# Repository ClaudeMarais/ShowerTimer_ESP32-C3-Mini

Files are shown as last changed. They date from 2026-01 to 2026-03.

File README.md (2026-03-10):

# Shower Timer using ESP32-C3 Super Mini

An Arduino project that automatically detects if a shower is running and shows a timer for how long you’ve been showering. TinyML using microphone data is used to determine if the shower is running or not.

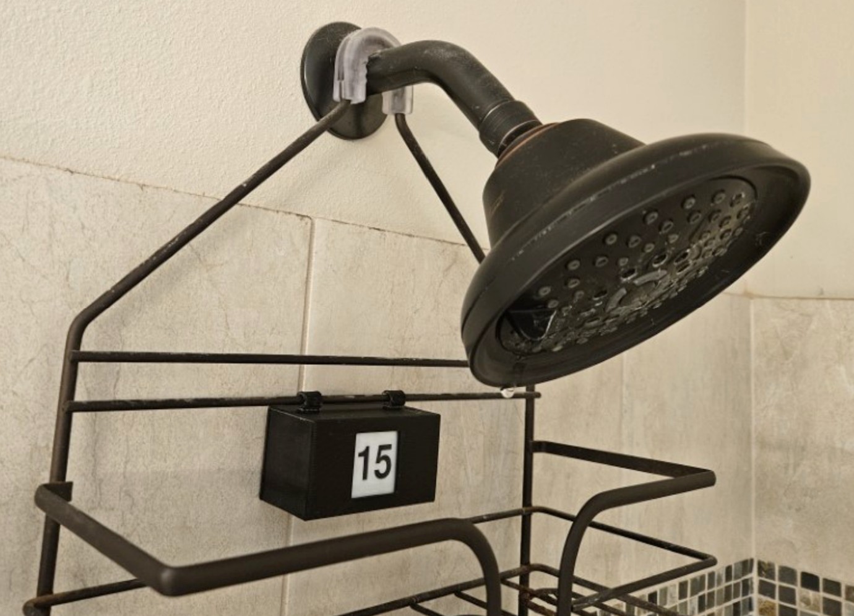
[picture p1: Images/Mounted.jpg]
Mounted


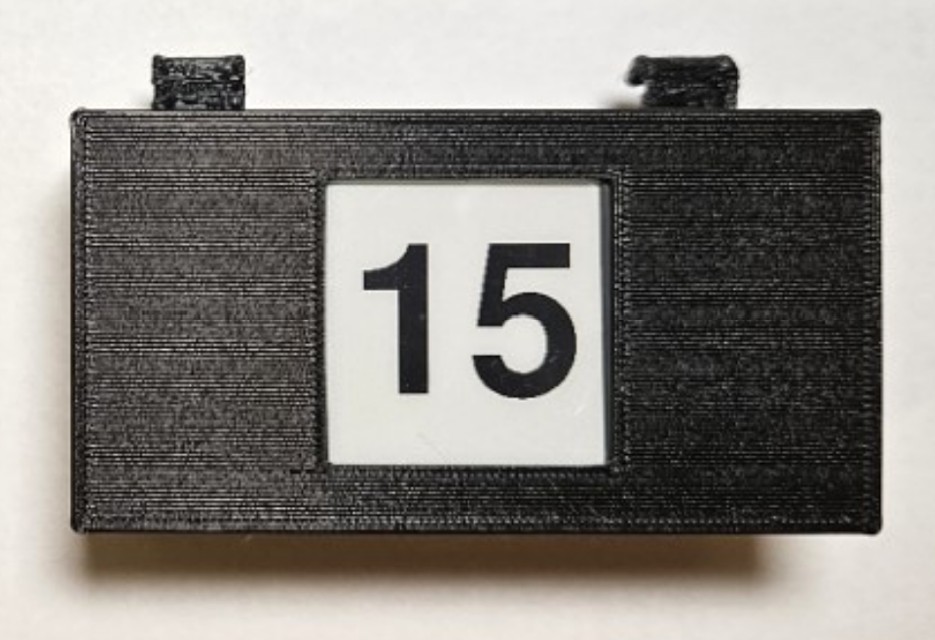
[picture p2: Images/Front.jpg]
Front


# Table of Contents
- [Introduction](#introduction)
- [Building your own](#building-your-own)
- [Building the device](#building-the-device)
- [Building the Arduino app](#building-the-arduino-app)
- [Creating your own ML model](#creating-your-own-ml-model)
- [Capturing ML training data](#capturing-ml-training-data)
- [Debugging inference results](#debugging-inference-results)
- [Detecting if the shower is ON/OFF](#detecting-if-the-shower-is-onoff)
- [Battery life](#battery-life)

---

# Introduction

An Arduino project that automatically detects if a shower is running and shows a timer for how long you’ve been showering. TinyML using microphone data is used to determine if the shower is running or not.

There are different ways to detect if the shower is on, e.g. small vibrations on the shower head could be detected using piezoelectric or gyroscope sensor. I tried a piezoelectric sensor, but the vibrations were too small to pick up, even though I could feel it with my hand. You could also modify the shower head pipe to install a small water flow sensor, but I didn't want to modify the shower. Therefore, I decided to use a small microphone.

This is a great machine learning application, since there are many different “white noises” in a bathroom, so it can be challenging to distinguish between them algorithmically. E.g. shower, hair dryer, filling a bathtub, toilet flush, extractor fan, electric toothbrush and shaver, vacuum cleaner, etc.

Since the device is in the shower, I had to waterproof it by cutting out two rubber gaskets, one sealing the display and one sealing the lid at the back. To protect the inside of the device from condensation, I applied transparent electronic silicone adhesive sealant on the circuit boards and solder points.

To conserve energy, an e-paper display is used which uses no power to display something. It only uses power to change something on the display, and that only happens once per minute while the shower is running.

This is considered version 1, which doesn't have fantastic battery life, since I didn't consider that even though the device goes into deepsleep, the microphone will still draw power at 1.4mA. This document includes a very detailed section on expected [battery life](#battery-life) and future improvements.

---

# Building your own

Building your own device involves
- [Building the actual device](#building-the-device)
- [Building the Arduino app](#building-the-arduino-app)
- Potentially [creating your own ML model](#creating-your-own-ml-model) if it doesn't work in your shower

<br>

| Folder | Note |
| --- |--- |
| ShowerTimer/ShowerTimer/ | Main Arduino project |
| ShowerTimer/ShowerTimer_inferencing.zip | Edge Impulse Arduino lib to install |
| ShowerTimer/3DModels/ | Models to 3D print |
| ShowerTimer/Android/CollectDataOnPhone  | Android project to collect ML training data |
| ShowerTimer/Android/DebugOnPhone | Android project to show debug info on phone |
| ShowerTimer/MLData.zip | My ML training audio recordings |

<br>

# Building the device

### **Image 1 - Components**

 - ESP32-C3 Super Mini
 - INMP441 i2s microphone
 - Waveshare 1.54inch E-Ink Display Module, black & white, 200x200 resolution, SPI interface
 - 0.8mm black silicone rubber
 - Battery holder for 3X 1.5V AAA batteries
 - PETG 3D printing filament

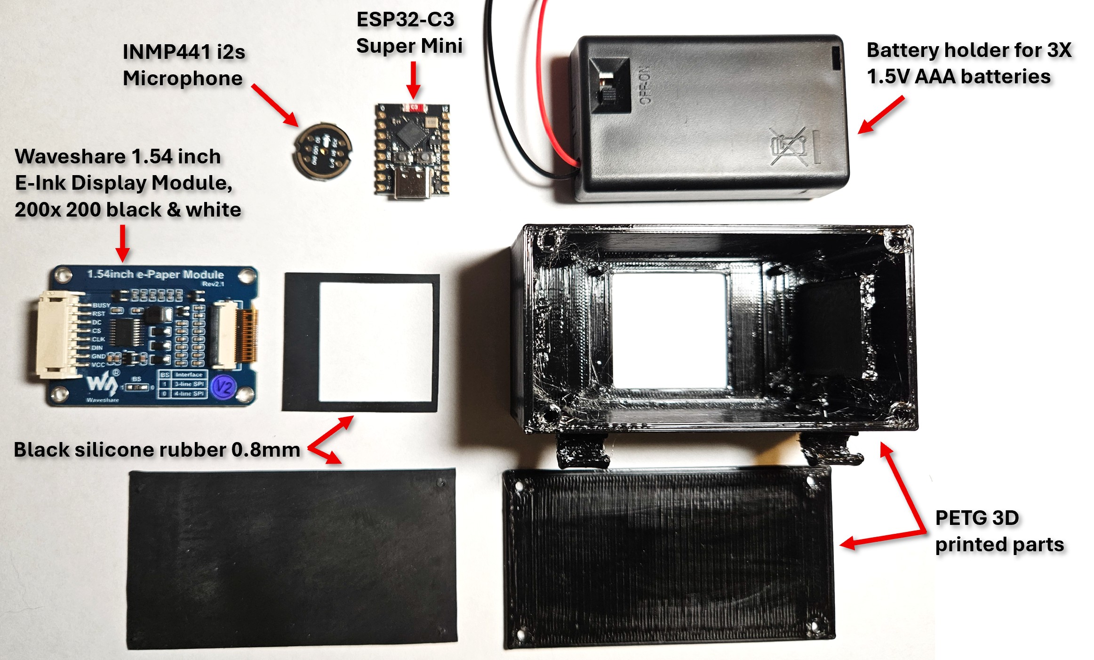
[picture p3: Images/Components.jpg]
Components


---

### **Image 2 - 3D design**

- [MatterControl](#https://www.matterhackers.com/store/l/mattercontrol/sk/MKZGTDW6) source files included if you need to make modifications
- Print with PETG or anything that won't warp with heat and humidity

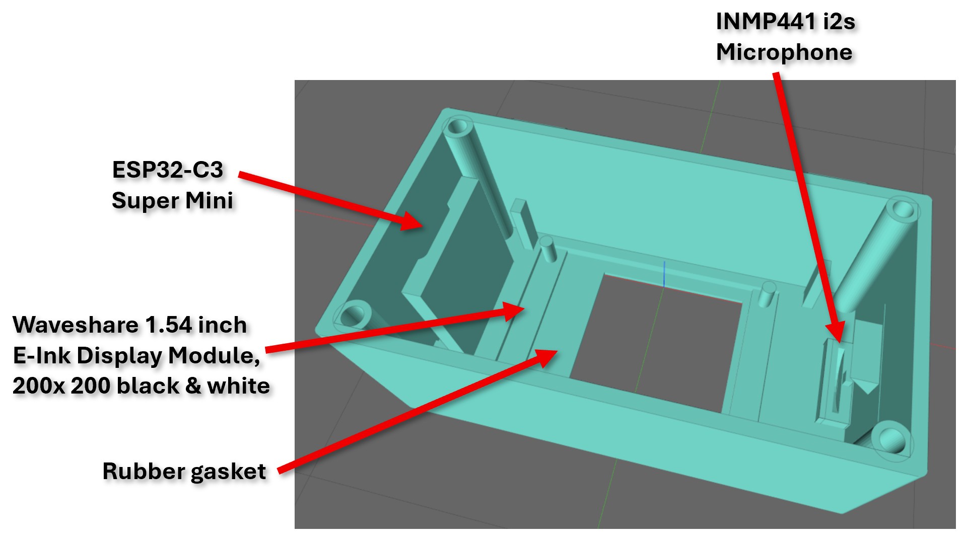
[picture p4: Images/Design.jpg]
Design


---

### **Image 3 - Component placement**

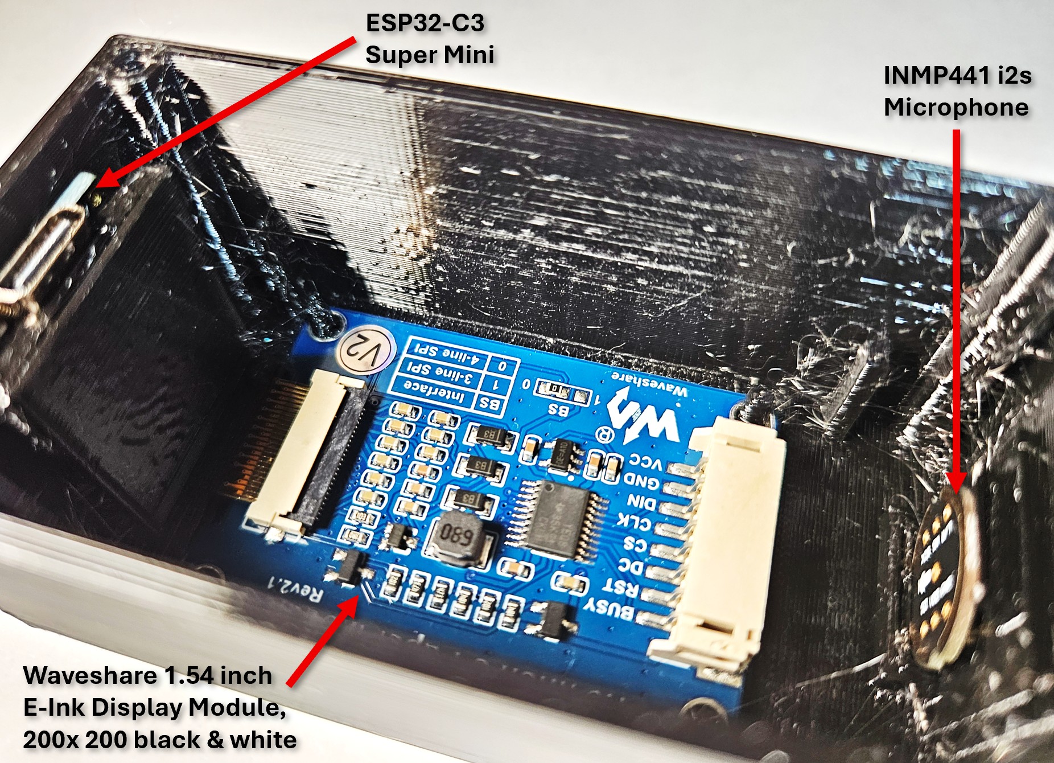
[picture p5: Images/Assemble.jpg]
Assemble


---

### **Image 4 - Wiring diagram**

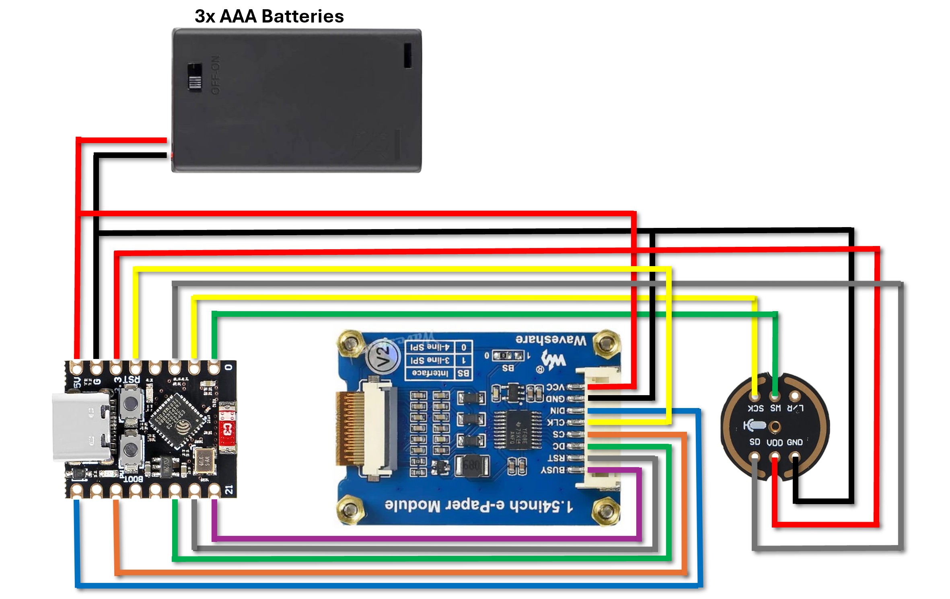
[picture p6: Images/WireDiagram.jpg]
WireDiagram

---

### **Image 5 - Soldered**

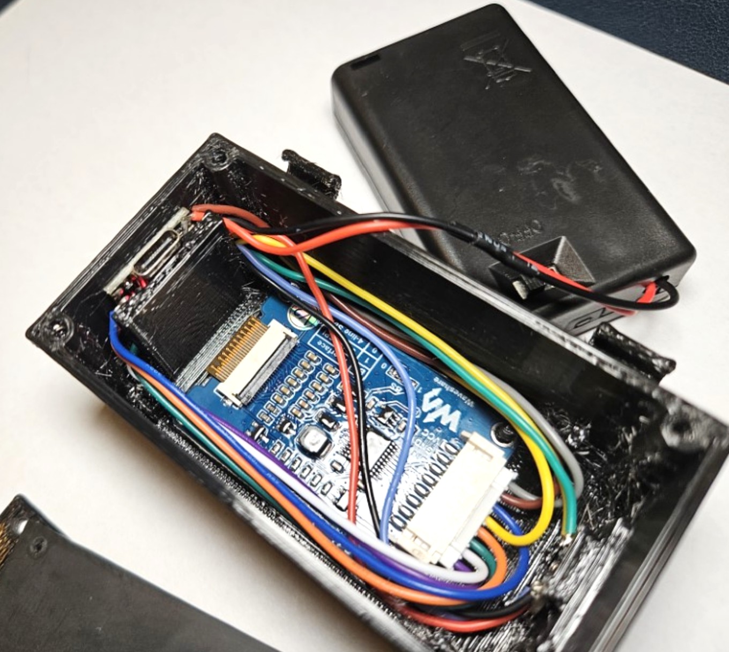
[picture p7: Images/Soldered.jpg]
Soldered


---

### **Image 6 - Waterproofing**

- Use sharp cutting tool or laser cutter to cut sealing gaskets out of 0.8mm silcone rubber sheet

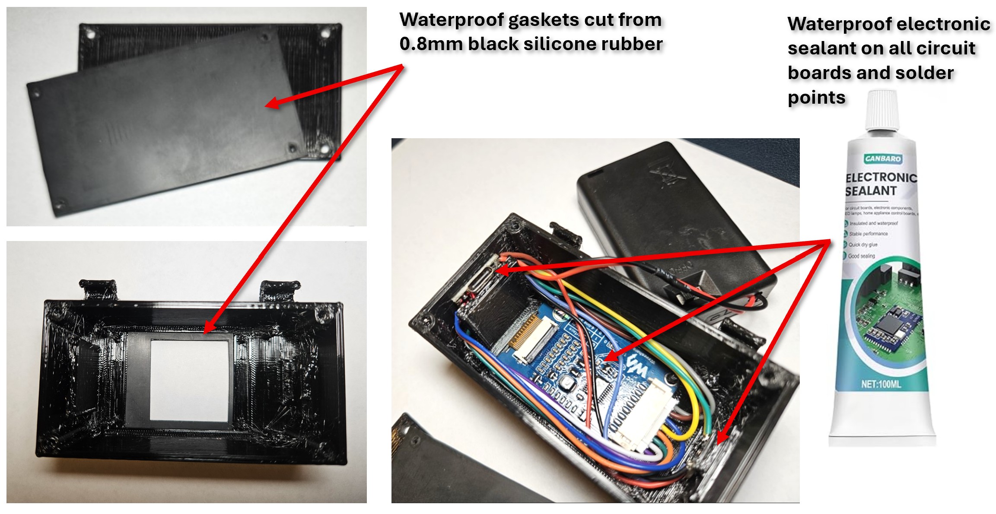
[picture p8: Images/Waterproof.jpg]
Waterproof


---

# Building the Arduino app

-	Install the Arduino IDE - https://www.arduino.cc/en/software
-	Configure Arduino IDE for ESP32 - https://randomnerdtutorials.com/installing-esp32-arduino-ide-2-0/
-	Install the below libraries - https://docs.arduino.cc/software/ide-v1/tutorials/installing-libraries/
    - Adafruit_GFX
    - [GxEPD2](https://github.com/ZinggJM/GxEPD2)
    - [ShowerTimer_inferencing](https://studio.edgeimpulse.com/public/879150/live) included as a zip file in this repro, generated by [Edge Impulse](https://www.edgeimpulse.com/)

For the final app, make sure to disable all defines for debugging and BLE connections. If not, your battery life will be extrememly short.

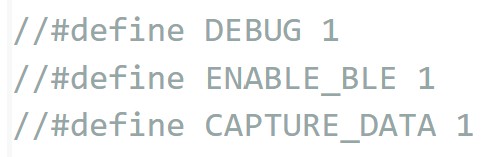
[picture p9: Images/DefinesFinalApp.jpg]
DefinesFinalApp


---

# Creating your own ML model

There’s a possibility that the device might not be accurate in your own bathroom, since your shower might sound different to mine, have different water pressure and water flow, different acoustics, different white noise, etc. In that case, you’ll need to build your own ML model using [Edge Impulse](#https://www.edgeimpulse.com/).

1) First, [build the device](#building-the-device) because you will need to close it up powered by batteries, and place it in your shower when capturing audio data. The shower will be on so you can’t have the device connected with wires that can get wet, and the acoustics will be different when the device is closed vs open.

2) Then, mount the device in your shower and [capture your own ML training data](#capturing-ml-training-data).

3) After that, clone my Edge Impulse project [ShowerTimer_inferencing](https://studio.edgeimpulse.com/public/879150/live) and add your own audio data to the project. It's a simple process, just follow documentation and examples.

4) Once added, click the button in Edge Impulse to retrain the model.

5) Click the button in Edge Impulse to export the model as an Arduino library. This will generate a .zip file that is similar to any other Ardauino library.

6) Replace the exsiting ShowerTimer_inferencing Arduino library with your own exported library.

7) Finally, rebuild the Arduino project.

---

# Capturing ML training data

ML will only work as well as your training data, i.e. bad training data will lead to poor results. Therefore, it's important to capture the training data exactly in the same way that you would use the device, i.e. similar location in the shower, similar everyday activities, device closed up for waterproofing, different water temperatures, etc.

Since the device will be closed up and installed in the shower, while the shower is running, data is captured and sent to your phone via BLE. This repo contains an Android app that connects with the device.

First, build the Arduino app with the following defines. Then, close it up and install it in the shower.

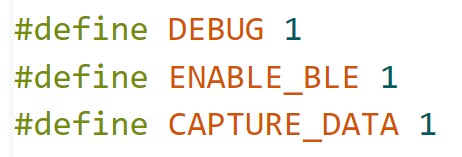
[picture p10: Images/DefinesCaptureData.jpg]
DefinesCaptureData
 

The folder "ShowerTimer/Android/CollectDataOnPhone" contains an Android app for recording the audio data. The device and phone will automatically connect via BLE, no need for any pairing. There are two buttons on the phone app to record data. Pressing one of these buttons will send a request to the Arduino device to reboot and immediately start an audio recording, and when done it will send it to the phone. You should see the progress bar at the top while recording and transfer is happening. The recordings can be found on your phone's storage in the folder "Internal storage/Documents/ShowerTimer/"

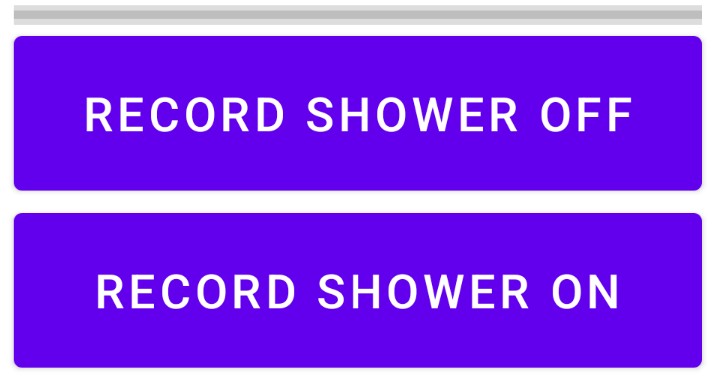
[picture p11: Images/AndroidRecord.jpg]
AndroidRecord


What to record? Well, you want to record as much of a variety of the day-to-day sounds in the bathroom. I suggest first recording as many sounds as possible with the shower door closed and the shower OFF. E.g. do multiple recordings for each case while the bathtub is being filled, extractor fan is on\off, hair dryer on difference speeds, vacuum cleaner sweeping through the bathroom, toilet flushes, electric toothbrush or shaver on, walking around, etc. Then, do many recordings when the shower is running, perhaps even redo some of previous scenarios where the shower was previously OFF, but now the shower is ON. I.e. do a few recordings of the hair dryer on and the shower is on. It’s very important to not just do recordings while the shower is running, but also when you are inside the shower, since this will create different sounds as larger water droplets form and splash against the side of the shower, etc. Also, the shower will sound different when running cold, warm or hot water, since the water pressure might be different in those cases.

---

# Debugging inference results

If you're lucky, you'll train the new model with your new data and everything just works. If not, you will need to somehow debug what the ML model produces, perhaps even while you are standing in the shower. The folder "ShowerTimer/Android/DebugOnPhone" contains an Android app that will display results from the Arduino device. This includes a loudness metric, the ML probability that the shower is on, and the actual result. The device and phone will automatically connect via BLE, no need for any pairing. Compile the Arduino app with the following defines.

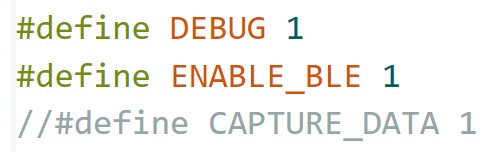
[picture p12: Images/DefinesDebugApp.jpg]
DefinesDebugApp


---

# Detecting if the shower is ON/OFF

Initially I thought this is a very simple problem to solve, since it’s very obvious when the shower is ON/OFF looking at the two graphics below which shows 250ms of audio data.

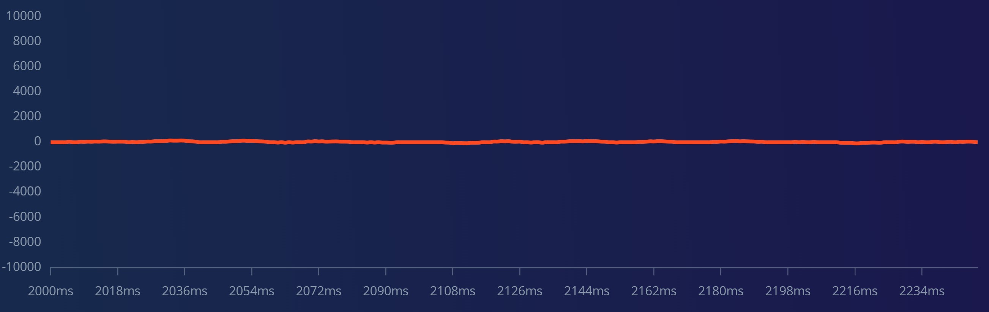
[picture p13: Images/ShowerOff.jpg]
ShowerOFF

*Figure 1 - Shower OFF*

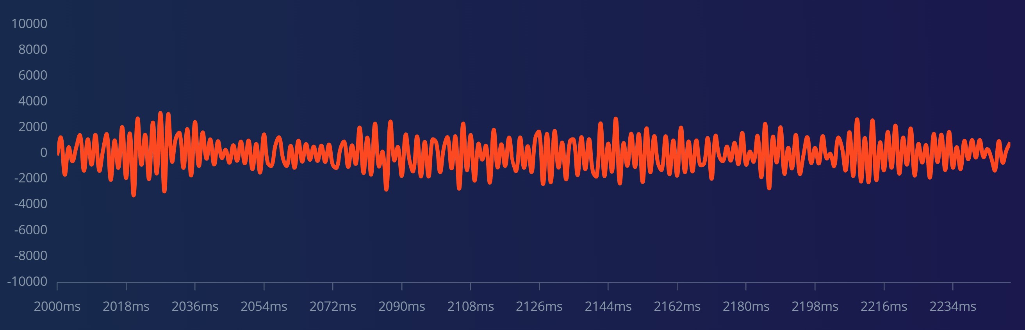
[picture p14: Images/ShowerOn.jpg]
ShowerON

*Figure 2 - Shower ON*

But, I quickly realized that this isn’t always the case, since there can be lots of “white” noises in a bathroom, including shower running, bathtub getting filled/drowned, extractor fan, toilet flush, hair dryer at different speeds, electric toothbrush and shaver, etc. Shower sounds also change when the water is hot, cold and with different water pressure. See the two graphs below.

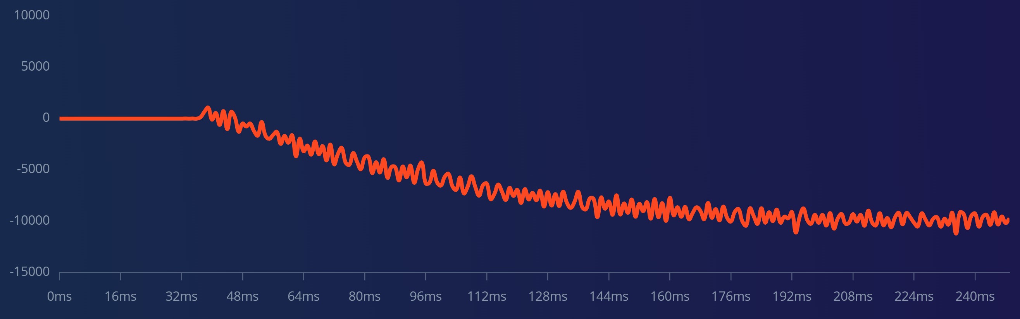
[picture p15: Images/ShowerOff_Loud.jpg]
ShowerOff_Loud

*Figure 3 - Hair dryer*

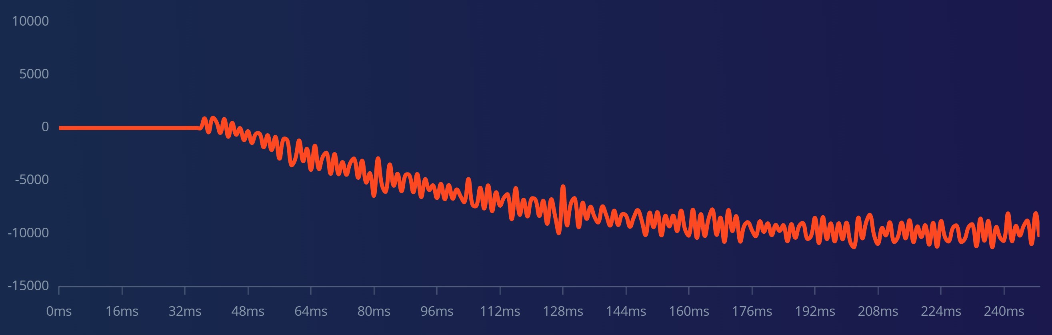
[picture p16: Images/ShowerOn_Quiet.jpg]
ShowerOn_Quiet

*Figure 4 - Shower ON*

 This let me decide to use [TinyML](#TinyML.org) as a solution, and it turned out to be fantastically reliable.

Initial results weren’t great though. The reason for this is that in order to save battery life, the device deepsleeps and right after it wakes up, it captures sound to process. The catch is that the microphone takes time to produce actual data, in my case 38ms, and after that it takes about 2 seconds to stabilize due to DC drift, we expect audio data to oscillate around zero. We expect data to show a straight line in a quiet environment, similar to Figure 1, but looking at the graph below there is a small section at the beginning of the graph that is just zero values, then a non-linear curve caused by DC drift, and only after about 2 seconds the data is stabilized, i.e. oscillating around zero.

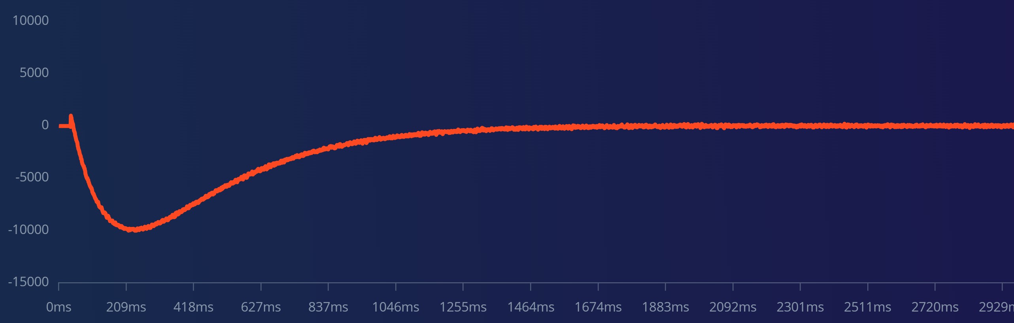
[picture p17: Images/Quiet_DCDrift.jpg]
Quiet_DCDrift

*Figure 5 - Non-linear audio data caused by DC drift*

 Training data was captured while the microphone already stabilized (Figure 1), but runtime inference was done while the microphone hasn’t produced data and was still unstable (Figure 3 & 4).

After realizing this, I captured new training data by starting the capture right after a wake from deepsleep. I also added a delay of 40ms after waking from a deepsleep to exclude any zeroed out data in the I2S DMA buffers from calling the API i2s_zero_dma_buffer(). This change gave an extremely reliable result, in fact I have yet to see a false positive or false negative!

I used Edge Impulse for my TinyML project, the full project with training data is available here: [Edge Impulse Shower Timer Project](https://studio.edgeimpulse.com/public/879150/live)

The design of the ML model is extremely simple. Audio MFE (Mel-frequency energy) is used as DSP (digital signal processing) to create ML features that is used as input into inferencing. The model itself basically consists of only two dense layers of 16 neurons each.

---

# Performance
Since the ML model is extremely simple, it is extremely fast to run on the microcontroller. Capturing the audio data and processing it take the majority of the time. A full cycle of the below takes 590ms on the ESP32-C3. For most of the day the bathroom will be quiet, and will run only for 260ms, which skips steps 4 and 5.
1)	Delay 40ms to wait for the microphone to start producing values
2)	Capture 210ms of audio data
3)	Determine if audio is loud enough, if not, no need to even run ML (<1ms)
4)	DSP (274 ms)
5)	ML inference (4ms)
6)	Deepsleep

---

# Battery Life 

This section summarizes three microphone/power architectures for the device:

1. **v1:** INMP441 always powered  
2. **v1.1:** INMP441 power-gated with a MOSFET  
3. **v2:** LP core + duty-cycled analog microphone  

It also explains how daily energy use is calculated so the numbers in each section are transparent and reproducible.

---

# How Daily Energy Use Is Calculated

All architectures share the same high-level behavior and the same usage assumptions:

- The household takes **4 showers per day**, each lasting **10 minutes**  
  → **40 minutes of shower time per day**
- The device wakes every 10 seconds to check whether the shower has started.
- Once the shower is confirmed ON, the device wakes **once per minute** to:
  - Run DSP + inference to confirm the shower is still active  
  - Refresh the e-paper display  
- DSP + inference requires ~590 ms of active ESP32 time at ~10 mA.
- However, most wakeups do NOT run the full 590 ms pipeline. 
  Each wake first performs a 260 ms low-cost audio capture to decide whether the sound is even loud enough to justify running the full ML pipeline.  
  - If quiet → go back to sleep  
  - If loud → run the full 590 ms DSP + inference  
- The microphone may be:
  - Always on (v1)
  - Powered only during wake intervals (v1.1)
  - Duty-cycled by the LP core (v2)

Daily energy use is computed from four components:

### 1. Baseline listening cost  
Energy consumed while the device is not in a shower state.  
This depends on:
- Wake frequency (every 10 seconds)
- Whether the microphone is powered continuously or only during wake windows
- Whether the LP core is running
- **Most wakeups only run the 260 ms "loudness check" not full DSP**

### 2. DSP + inference cost during showers  
During the **40 minutes of total shower time per day**, the device performs one full DSP window per minute.

- Each DSP + inferencing window: **590 ms at ~10 mA**
- Total windows per day: **40**

### 3. E-paper refresh cost  
The display updates once per minute during a shower.

- 40 refreshes per day  
- Each refresh: **2 seconds at ~8 mA**
- Total: **~0.18 mAh/day**

### 4. Shower off, but bathroom noisy  
If the environment produces ~1 hour/day of loud noise, the device may run additional DSP + inference windows.

This adds **~0.33 mAh/day**.

---

# 1. INMP441 Always On (Current v1 Hardware)

The INMP441 is an I²S digital microphone with no sleep mode.  
If wired directly to VDD (as in v1), it remains powered even during deep sleep.

On the **ESP32-C3 Super Mini**, measurements show:

- **Board deep-sleep baseline (no mic):** ~**0.7 mA**  
- **Deep sleep with mic powered:** ~**0.9 mA**  
  → Mic adds ~**0.2 mA** incremental current in deep sleep.

## Characteristics

| Property | Value |
|---|---|
| Microphone type | Digital (I²S) |
| Board deep-sleep baseline | ~0.7 mA |
| Mic current (always powered, incremental) | ~0.2 mA |
| ESP32 wake pattern | Every 10 s (shower OFF), once per minute (shower ON) |
| Loudness pre-check | 260 ms per wake |
| Full DSP + inference | Only when loud enough (or once per minute during shower) |
| E-paper refresh | Once per minute during showers |

## Daily Energy Use

| Component | mAh/day |
|---|---|
| Board deep-sleep baseline (0.7 mA × 24 h) | **16.8 mAh/day** |
| INMP441 incremental (0.2 mA × 24 h) | **4.8 mAh/day** |
| ESP32 + logic during wakes | ~6.6 mAh/day |
| E-paper | 0.18 mAh/day |
| **Total** | **~28.4 mAh/day** |

## Battery Life

| Battery | Life |
|---|---|
| 1500 mAh AAA | **~1.7 months** |
| 2000 mAh LiPo (1600 usable) | **~1.9 months** |

# Why Deep Sleep Is ~0.7 mA on the ESP32-C3 Super Mini (Not Microamps)

Espressif’s datasheet advertises **10–20 µA** deep-sleep current — and that is accurate **for the bare ESP32-C3 chip or module**.

However, the **ESP32-C3 Super Mini** is a *development board*, and includes extra components that remain powered even in deep sleep:

| Component | Typical Current | Notes |
|---|---|---|
| **Red power LED** | 0.3–1.0 mA | Always on, powered from 3.3 V |
| **3.3 V regulator quiescent current** | 50–150 µA | Depends on regulator model |
| **USB-serial chip** | 0.3–1.0 mA | Powered whenever 5 V is present; off when powering via 3.3 V |
| **ESP32-C3 deep sleep** | 10–20 µA | As advertised |

When powering the Super Mini from **3.3 V directly**, the USB-serial chip is off, but the LED and regulator remain active.  
This results in a **real, measured deep-sleep current of ~0.7 mA**, which matches your measurements.

To reach microamp deep sleep, you would need:

- No power LED  
- No USB‑serial chip  
- A low-Iq regulator  
- A custom PCB or bare module  

The Super Mini is excellent for prototyping, but it cannot reach datasheet deep-sleep numbers without hardware modification.

---

# 2. INMP441 Controlled by MOSFET (v1.1 Concept)

In this design, the INMP441 is power-gated using a MOSFET.  
The microphone is powered only during wake intervals.

Measurements show:

- **Deep sleep with mic power-gated:** ~**0.7 mA** (board baseline)  
- **Deep sleep with mic always powered:** ~**0.9 mA**  
  → Power-gating saves ~**0.2 mA** continuously in deep sleep.

There is also a **small active-mode overhead**:

- **Init mic without MOSFET:** ~**20.1 mA**  
- **Init mic with MOSFET:** ~**23.2 mA**  
  → MOSFET path adds ~**3.1 mA** only during short “mic on” windows (260 ms pre-checks + 590 ms DSP windows).  
Because those windows are a tiny fraction of the day, the **0.2 mA 24/7 deep-sleep savings dominates**.

## Characteristics

| Property | Value |
|---|---|
| Microphone type | Digital (I²S) |
| Board deep-sleep baseline | ~0.7 mA |
| Mic current | 0 mA outside wake windows (power-gated) |
| ESP32 wake pattern | Every 10 s (shower OFF), once per minute (shower ON) |
| Loudness pre-check | 260 ms per wake |
| Full DSP + inference | Only when loud enough (or once per minute during shower) |
| E-paper refresh | Once per minute during showers |

## Daily Energy Use

| Component | mAh/day |
|---|---|
| Board deep-sleep baseline (0.7 mA × 24 h) | **16.8 mAh/day** |
| ESP32 + mic during wakes | ~6.6 mAh/day |
| E-paper | 0.18 mAh/day |
| **Total** | **~23.6 mAh/day** |

## Battery Life

| Battery | Life |
|---|---|
| 1500 mAh AAA | **~2.1 months** |
| 2000 mAh LiPo (1600 usable) | **~2.2 months** |

## Summary

- Power-gating the INMP441 increases battery life from **~1.7 months → ~2.1 months** on the ESP32‑C3 Super Mini.  
- The 260 ms loudness pre-check avoids unnecessary DSP work.  
- The MOSFET introduces a small active-mode overhead (~3.1 mA during short mic-on windows), but the **0.2 mA deep‑sleep savings 24/7 still wins overall**.

---

# 3. LP Core + Duty-Cycled Analog Microphone (v2 Concept)

This design replaces the INMP441 with a low-power analog MEMS microphone and uses:

- An ESP32-**S3** with LP (low power) core to read an envelope detector or ADC with simple analog microphone
- Main cores wake only when loudness is sustained  
- Shower-ON behavior remains: one wake per minute
- A duty cycle (e.g., 200 ms ON every 2 s → 10%)  

## Characteristics

| Property | Value |
|---|---|
| Microphone type | Analog MEMS |
| Mic current (ON) | ~0.6 mA |
| Duty cycle | 10% |
| LP core current | ~0.05 mA |
| Loudness pre-check | Done by LP core, extremely cheap |
| Full DSP + inference | Once per minute during showers |
| E-paper refresh | Once per minute during showers |

## Daily Energy Use

| Component | mAh/day |
|---|---|
| Duty-cycled mic + LP core | 2.64 mAh/day |
| DSP + inference | 0.065 mAh/day |
| E-paper | 0.18 mAh/day |
| **Total** | **~2.89 mAh/day** |
| With 1 noisy hour/day | **~3.22 mAh/day** |

## Battery Life

| Battery | Quiet Day | Noisy Hour |
|---|---|---|
| 1500 mAh AAA | **~17.3 months** | **~15.5 months** |
| 2000 mAh LiPo (1600 usable) | **~18.4 months** | **~16.5 months** |

## Summary

- LP core + analog mic enables **~18 months** battery life.
- The LP core handles loudness checks with almost no cost.
- This is the most efficient architecture.

---

# Overall Comparison

| Architecture | Avg Current | Daily mAh | Battery Life (AAA) | Notes |
|---|---|---|---|---|
| **1. INMP441 always on** | ~**1.18 mA** | ~**28.4 mAh** | **~1.7 months** | Current v1 (Super Mini) |
| **2. INMP441 + MOSFET** | ~**0.98 mA** | ~**23.6 mAh** | **~2.1 months** | v1.1 (Super Mini) |
| **3. LP core + analog mic** | ~**0.12 mA** | ~**2.9 mAh** | **~17.3 months** | v2 concept (ESP32-S3) |

---

# Key Takeaways

- Most wakeups only run a **260 ms loudness check**, not full DSP.
- Waking once per minute during a shower dramatically reduces DSP work.
- Power-gating the INMP441 increases battery life only marginally.
- LP core + analog mic reaches **~17-18 months**.
- The longer the shower runs, the more efficient the device becomes.

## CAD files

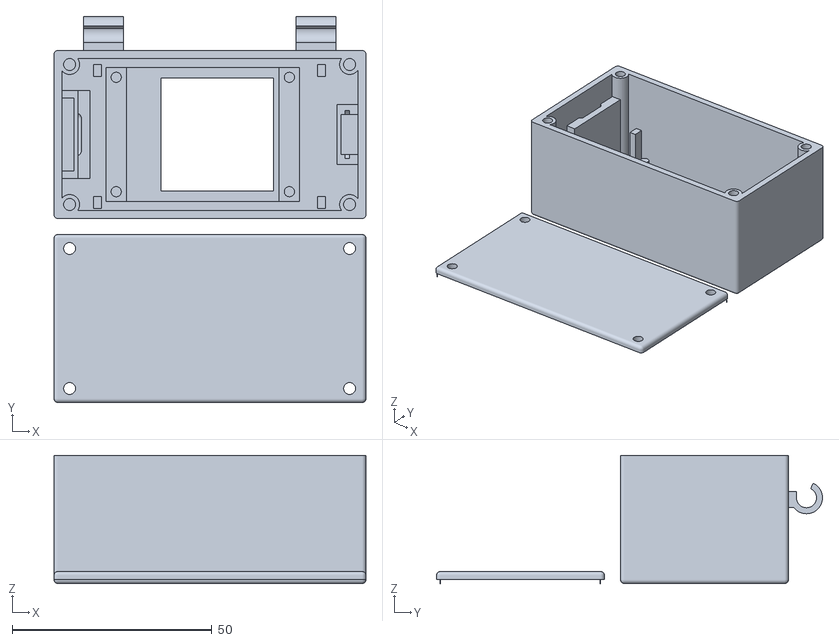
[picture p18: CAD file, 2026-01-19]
3DModels/AllParts.stl
78.0 x 96.5 x 32.0

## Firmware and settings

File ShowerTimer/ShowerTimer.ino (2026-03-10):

// An Arduino project that automatically detects if a shower is running and shows a timer for how long you’ve been showering.
// TinyML using microphone data is used to determine if the shower is running or not. This is a great machine learning application,
// since there are many different “white noises” in a bathroom, so it’s challenging to distinguish between them algorithmically.
// E.g. shower, hair dryer, filling a bathtub, toilet flush, extractor fan, electric toothbrush and shaver, vacuum cleaner, etc.
//
// NOTE: There’s a possibility that the device might not be accurate in your own bathroom, since your shower might sound different
//       to mine, have different water pressure, different acoustics, different white noise, etc. In that case, refer to the section
//       "Building your own" in the README.md document.
//
// NOTE: This is considered version 1, which doesn't have fantastic battery life, since I didn't consider that even though the
//       device goes into deepsleep, the microphone will still draw power at 1.4mA. Refer to the section "Battery life" in the
//       README.md file, which also includes ideas for future improvements.
//
// Hardware:
// - ESP32-C3 Super Mini
// - INMP441 i2s microphone
// - Waveshare 1.54inch E-Ink Display Module, black & white, 200x200 resolution, SPI interface
// - Battery holder for 3X 1.5V AAA batteries

//#define DEBUG 1           // Only define this during development, since it will output useful debug text to Serial
//#define ENABLE_BLE 1      // Only define this if you need to send debug/fine tuning information to your phone using BLE
//#define CAPTURE_DATA 1    // Only define this if you're capturing audio data for ML training that will be sent to your phone using BLE

// Data capturing requires BLE
#ifdef CAPTURE_DATA
#define ENABLE_BLE 1
#endif

// Pin connections to INMP441 I2S microphone
#define I2S_WS       A0
#define I2S_SCK      A1
#define I2S_SD       A2

// Pin connections to SPI e-paper display
#define DISPLAY_CS   7
#define DISPLAY_DC   10
#define DISPLAY_RST  20
#define DISPLAY_BUSY 21

// Below this threshold is too quiet for the shower to be ON. This was determined experimentally.
const int32_t AvgAmplitudeThreshold = 100;

// 12 second time intervals to see if shower turned ON, i.e. check 5 times per minute
const unsigned long TimeIntervalInSecondsWhileShowerOFF = 12;
const unsigned long TimeIntervalInMsWhileShowerOFF = TimeIntervalInSecondsWhileShowerOFF * 1000;

// 60 second time intervals to see if shower turned OFF. To save battery power, we only need to check once a minute to see if the shower turned OFF
#ifdef DEBUG
const unsigned long TimeIntervalInSecondsWhileShowerON = 10;
#else
const unsigned long TimeIntervalInSecondsWhileShowerON = 60;
#endif
const unsigned long TimeIntervalInMsWhileShowerON = TimeIntervalInSecondsWhileShowerON * 1000;

unsigned long StartTime = 0;

// RTC_DATA_ATTR keeps these variable alive during deep sleep
RTC_DATA_ATTR uint32_t g_ShowerOnTimeInSeconds = 0;
RTC_DATA_ATTR bool g_bIsShowerOn = false;               // Global variable to keep track of the state of the shower over the full 12 sec time interval, even during deepsleep
RTC_DATA_ATTR bool g_bNeedDoubleCheck = false;          // Flag to indicate if we need to double-check that shower is actually off in case of a false negative

// Termonlogy: A false negative is when we detect the shower turned OFF, but it is still actually ON
//             A false positive is when we detect the shower turned ON, but it is actually still OFF

#ifdef ENABLE_BLE
// The name of our Bluetooth peripheral
#define PERIPHERAL_NAME "ShowerTimerDevice"

// Custom generated UUIDs for this project (using https://www.uuidgenerator.net/)
#define SHOWER_TIMER_SERVICE_UUID "0372c18f-6bb1-4c2f-a8c0-8125d51c41a4"
#define DATA_FROM_PHONE_TO_ARDUINO_CHARACTERISTIC_UUID "157bd625-aa1f-474a-8e26-251cf2ca626e"
#define DATA_FROM_ARDUINO_TO_PHONE_CHARACTERISTIC_UUID "56de086a-9c2a-4765-8761-3b42f6398673"

#endif  // ENABLE_BLE

#include "Utils.h"
#include "TinyML.h"

static const uint32_t AudioSampleRate = EI_CLASSIFIER_FREQUENCY;
static const uint32_t NumSamplesInAudioBuffer = EI_CLASSIFIER_RAW_SAMPLE_COUNT;
DMA_ATTR static int16_t AudioBuffer[NumSamplesInAudioBuffer];   // DMA_ATTR keeps this buffer in DMA-safe internal RAM for I2S

#include "Audio.h"
#include "Display.h"

#ifdef CAPTURE_DATA
#include "CaptureData.h"
#endif  // CAPTURE_DATA

#ifdef ENABLE_BLE
#include "BLEPeripheral.h"
char BLEText[32];
#endif  // ENABLE_BLE

#define ERROR_AUDIO_SETUP     1
#define ERROR_AUDIO_GET_DATA  2
#define ERROR_CAPTURE_DATA    3

// Perform audio preprocessing and ML inference to detect shower state
// Returns true if shower is detected as ON, false if OFF
// Also sets avgAmplitude and probability output parameters
bool DetectShowerState(int32_t& avgAmplitude, float& probability, const char* debugPrefix = "")
{
  bool bIsShowerOnRightNow = false;
  probability = 0.0f;
  
  avgAmplitude = 0;
  Audio::PreprocessData(AudioBuffer, NumSamplesInAudioBuffer, 5, avgAmplitude);
  
  // If the audio is loud enough, run inference
  if (avgAmplitude > AvgAmplitudeThreshold)
  {
    DebugPrintf("%sSound loud enough for shower to potentially be ON (Avg amplitude = %d)\n", debugPrefix, avgAmplitude);
    
#ifdef ENABLE_BLE
    snprintf(BLEText, sizeof(BLEText), "Maybe ON\n%d", avgAmplitude);
    SendBLEText(BLEText);
    delay(1000);
#endif  // ENABLE_BLE
    
    bIsShowerOnRightNow = TinyML::IsShowerOn(AudioBuffer, NumSamplesInAudioBuffer, probability);
  }
  else
  {
    DebugPrintf("%sSound too quiet, therefore shower must be OFF (Avg amplitude = %d)\n", debugPrefix, avgAmplitude);
    
#ifdef ENABLE_BLE
    snprintf(BLEText, sizeof(BLEText), "Too quiet\n%d", avgAmplitude);
    SendBLEText(BLEText);
    delay(1000);
#endif  // ENABLE_BLE
  }
  
  return bIsShowerOnRightNow;
}

void setup()
{
  // Everytime the device wakes up from deepsleep, Setup() will run, so we need to include any processing time from Setup() when calculating how long
  // to deepsleep to keep a strict 12 second time interval while the shower is OFF, and 60 seconds while the shower is ON
  StartTime = millis();

  // After the device powers on, immediatly initialize the microphone
  while (!Audio::Setup(AudioSampleRate))
  {
    ShowError(ERROR_AUDIO_SETUP);
    delay(1000);
  }

#ifdef CAPTURE_DATA
  while (!CaptureData::CaptureData())
  {
    ShowError(ERROR_CAPTURE_DATA);
    delay(1000);
  }
#endif  // CAPTURE_DATA

  while (!Audio::GetData(AudioBuffer, NumSamplesInAudioBuffer))
  {
    ShowError(ERROR_AUDIO_GET_DATA);
    delay(1000);
    return;
  }

#ifdef DEBUG
  Serial.begin(115200);
  delay(1000);
#endif

  DebugPrintf("\n\n********* ShowerTimer with ESP32-C3 Super Mini *********\n\n");

#ifdef ENABLE_BLE
  // Setup BLE to communicate with phone
  BLEPeripheral::Setup();

  // Wait for BLE to connect
  while (!BLEPeripheral::isCentralConnected)
  {
    delay(100);
  }
 
  // Although BLE is connected by now, it seems that we need to add an extra wait to make sure all the BLE callbacks are setup and ready to go
  delay(1000);
#endif  // ENABLE_BLE

  // Double-check from previous wake cycle just in case there was a false negative
  if (g_bNeedDoubleCheck)
  {
    DebugPrintln("Performing double-check after potential false negative shower OFF detection");
    g_bNeedDoubleCheck = false; // Clear the flag
    
    // Perform the detection using our common function
    bool bIsShowerOnRightNow = false;
    float probability = 0.0f;
    int32_t avgAmplitude = 0;
    
    bIsShowerOnRightNow = DetectShowerState(avgAmplitude, probability, "Double-check: ");
    
    if (bIsShowerOnRightNow)
    {
      // False negative detected! Shower is actually still ON
      DebugPrintln("Double-check FAILED: Shower is actually still ON - was a false negative!");

    
#ifdef ENABLE_BLE
      snprintf(BLEText, sizeof(BLEText), "False negative\n%1.2f", probability);
      SendBLEText(BLEText);
#endif  // ENABLE_BLE

      // Revert the state
      g_bIsShowerOn = true;

      // Continue with normal shower ON logic
      auto oldShowerOnTimeInMinutes = g_ShowerOnTimeInSeconds / 60;
      g_ShowerOnTimeInSeconds += TimeIntervalInSecondsWhileShowerOFF; // Add the 12 seconds we slept
      auto newShowerOnTimeInMinutes = g_ShowerOnTimeInSeconds / 60;
      
      if (newShowerOnTimeInMinutes != oldShowerOnTimeInMinutes)
      {
        // Update the display with the new number of minutes ON time
        Display::Init();
        Display::ShowNumber(newShowerOnTimeInMinutes);
        Display::PowerOff();
      }
      
      SleepUntilNextTimeInterval(TimeIntervalInMsWhileShowerON, StartTime);
      return;
    }
    else
    {
      // Double-check confirmed shower is OFF
      DebugPrintln("Double-check PASSED: Shower is confirmed OFF");
      
#ifdef ENABLE_BLE
      snprintf(BLEText, sizeof(BLEText), "Confirmed OFF\n%1.2f", probability);
      SendBLEText(BLEText);
#endif  // ENABLE_BLE
      
      // Continue with normal shower OFF logic     
      SleepUntilNextTimeInterval(TimeIntervalInMsWhileShowerOFF, StartTime);
      return;
    }
  }

  // Perform main shower detection
  bool bIsShowerOnRightNow = false;
  float probability = 0.0f;
  int32_t avgAmplitude = 0;
  
  bIsShowerOnRightNow = DetectShowerState(avgAmplitude, probability);

  unsigned long timeIntervalInSeconds;
  unsigned long timeIntervalInMs;

  if (bIsShowerOnRightNow)  // Right now the shower is ON, but we need to determine if it just turned ON, or has it been ON already
  {
    timeIntervalInSeconds = TimeIntervalInSecondsWhileShowerON;
    timeIntervalInMs = TimeIntervalInMsWhileShowerON;

    auto oldShowerOnTimeInMinutes = g_ShowerOnTimeInSeconds / 60;

    if (!g_bIsShowerOn)
    {
      // Shower just turned ON
      DebugPrintln("Shower just turned ON");

#ifdef ENABLE_BLE
      snprintf(BLEText, sizeof(BLEText), "Turned ON\n%1.2f", probability);
      SendBLEText(BLEText);
#endif  // ENABLE_BLE

      g_bIsShowerOn = true;
      g_ShowerOnTimeInSeconds = 0;

      // Update the display with 0 minutes of ON time
      Display::Init();
      Display::ShowNumber(0);
      Display::PowerOff();
    }
    else
    {
      // Shower still running
      DebugPrintln("Still running");

#ifdef ENABLE_BLE
      snprintf(BLEText, sizeof(BLEText), "Still running\n%1.2f", probability);
      SendBLEText(BLEText);
#endif  // ENABLE_BLE

      g_ShowerOnTimeInSeconds += timeIntervalInSeconds;
      auto newShowerOnTimeInMinutes = g_ShowerOnTimeInSeconds / 60;

      if (newShowerOnTimeInMinutes != oldShowerOnTimeInMinutes)
      {
        // Update the display with the new number of minutes ON time
        Display::Init();
        Display::ShowNumber(newShowerOnTimeInMinutes);
        Display::PowerOff();
      }
    }
  }
  else  // Right now the shower is OFF, but we need to determine if it just turned OFF, or has it been OFF already
  {
    timeIntervalInMs = TimeIntervalInMsWhileShowerOFF;

    if (g_bIsShowerOn)
    {
      DebugPrintln("Shower just turned OFF - setting up double-check");

      // NOTE: Here we could clear the display if we detect the shower turned OFF, but it's more interesting to keep showing the shower duration
      //       until the shower turns ON again. This way you can see for how long the previous person showered

#ifdef ENABLE_BLE
      snprintf(BLEText, sizeof(BLEText), "Turned OFF\n%1.2f", probability);
      SendBLEText(BLEText);
#endif  // ENABLE_BLE
      // Set flag for double-check and temporarily mark as OFF
      g_bNeedDoubleCheck = true;
      g_bIsShowerOn = false;
    }
    else
    {
      DebugPrintln("Shower is OFF");

#ifdef ENABLE_BLE
      snprintf(BLEText, sizeof(BLEText), "Shower is OFF\n%1.2f", probability);
      SendBLEText(BLEText);
#endif
    }
    
    g_bIsShowerOn = false;
  }

  // Go into deepsleep until the next time interval
  SleepUntilNextTimeInterval(timeIntervalInMs, StartTime);
}

void loop()
{
}

// The device does not have a realtime clock, so we need to as accurately as possible calculate for how long we need to
// deepsleep in order to keep our 12 second time interval, otherwise the shower ON duration will be calculated wrongly
void SleepUntilNextTimeInterval(unsigned long intervalInMs, unsigned long startTimeInMs)
{
  auto now = millis();
  auto elapsed = now - startTimeInMs;
  DebugPrintf("Total elapsed time = %lu ms\n", elapsed);

  // If processing took longer than the time interval, sleep minimally
  if (elapsed > intervalInMs)
  {
    // Sleep 1 ms to avoid immediate re-wake
    Audio::Shutdown();
    esp_sleep_enable_timer_wakeup(1000ULL);
    esp_deep_sleep_start();
  }

  unsigned long remainingTimeInMs = intervalInMs - elapsed;
  uint64_t remainingTimeInUs = (uint64_t)remainingTimeInMs * 1000ULL;

  DebugPrintf("Deepsleep for %lu ms\n", remainingTimeInMs);

  Audio::Shutdown();
  esp_sleep_enable_timer_wakeup(remainingTimeInUs);
  esp_deep_sleep_start();
}

// Show an error number on the display
void ShowError(const int32_t number)
{
  Display::Init();
  Display::ShowNumber(-number);
  Display::PowerOff();
}

#ifdef ENABLE_BLE
void SendBLEText(char* text)
{
  if (BLEPeripheral::isCentralConnected && text)
  {
    BLEPeripheral::SendData((unsigned char*)text, strlen(text));
  }
  delay(250);
}
#endif  // ENABLE_BLE

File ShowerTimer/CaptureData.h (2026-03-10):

// Functions that can be used to record audio data and send it to a phone using BLE. The recorded data is used for ML training data.
//
// One thing that's interesting for capturing data, is that we need to capture the data in exactly the same way that the actuall app
// would capture data, which is capturing the data right after the device wakes up from deepsleep. Deepsleeping the device is required
// to maximise battery life. But, since there is DC drift on the audio data for about 2 seconds right after the device reboots, we need
// to capture data by first deepsleeping, so that we can capture training data with the same DC drift. See the readme file for more details.
//
// The data capture flow is:
//  1) Boot device
//  2) Connect to phone using BLE
//  3) Wait for a recording request from the phone
//  4) Deepsleep for 1 second
//  5) Wake up
//  6) Immediately capture audio data
//  7) Connect to phone using BLE
//  8) Transfer audio data to phone

#ifndef _CAPTURE_DATA
#define _CAPTURE_DATA

#include "Audio.h"
#include "BLEPeripheral.h"

namespace CaptureData
{
  // Instead of streaming audio data to the phone, we just do short recordings into a big DMA copy buffer and then transfer the whole buffer to the phone.
  // You can easily record 3 seconds at 16KHz, or 6 seconds at 8KHz into a static buffer on the ESP32-C3. Our ML data window of audio data is only 250ms,
  // so 2 seconds capture more than enough useful data in one recording.
  const uint32_t TotalSecondsToRecord = 2;

  // Audio data size info
  const uint32_t BytesPerSecond = Audio::NumChannels * AudioSampleRate * Audio::BitsPerSample / 8;
  const uint32_t TotalAudioSizeInBytes = TotalSecondsToRecord * BytesPerSecond;
  const uint32_t TotalNumSamples = TotalSecondsToRecord * AudioSampleRate;
  const uint32_t DMACopyBufferSizeInBytes = BytesPerSecond * TotalSecondsToRecord;  // Size of the DMA copy buffer that can hold audio data for the duration of TotalSecondsToRecord
  const uint32_t NumSamplesInDMACopyBuffer = DMACopyBufferSizeInBytes / (Audio::BitsPerSample / 8);

  // Static audio buffer for a duration of TotalSecondsToRecord. We will only record a few seconds, so we can use one big DMA copy buffer.
  // If the duration is too long for one big DMA copy buffer, this app won't work, since sending BLE packets is very slow. If we need to
  // send longer audio, then the data can first be copied to an SD card or perhaps the data can be transferred over Wifi on a seperate thread
  DMA_ATTR static uint8_t DMACopyBuffer[DMACopyBufferSizeInBytes];  // I2S DMA buffers are copied into this buffer when calling i2s_read()

  // Header commands to start communication with phone
  uint8_t CommandStartRecording[] = { 'R', 'E', 'C', 'O', 'R', 'D' };           // Let phone know recording started and how for how many seconds, so that a progress bar can be shown
  uint8_t CommandStartTransfer[] = { 'T', 'R', 'A', 'N', 'S', 'F', 'E', 'R'};   // Let phone know that transfer of audio data will start and how many bytes to expect

  // BLE packets are only 20 bytes and has to be sent a minimum of 7.5ms apart
  const uint32_t MaxBLEBytesPerPacket = 20;
  const uint32_t DelayForPhoneUIToUpdate = 250;   // in milliseconds

  // This is set to true in a callback function when data is received from phone
  volatile bool bRequestRecording = false;

  // Set this true right before going into deepsleep so that we know that we woke up to start a recording in the Setup function
  RTC_DATA_ATTR bool bSendAudioToPhoneOnStartup = false;

  // After receiving a request to record audio, we'll first deepsleep, wakeup and then record audio
  const uint64_t DeepSleepDurationInSeconds = 1ULL;
  const uint64_t DeepSleepDurationInMicroSeconds = DeepSleepDurationInSeconds * 1000000ULL;

  // Callback that can process values as soon as they are received from the phone in the Notify callback
  // We actually don't care what the data is, the only time data will be received is when the phone asks
  // to start audio recording
  void NewDataReceivedFromPhoneCallback(uint8_t data)
  {
    bRequestRecording = true;
  }

  // Setup
  void SetupBLE()
  {
    DebugPrintln("CaptureData::Setup()");

    // Setup Bluetooth to communicate with phone
    BLEPeripheral::Setup();
    BLEPeripheral::SetOnValuesReceivedCallback(NewDataReceivedFromPhoneCallback);

    // Wait for BLE to connect
    while (!BLEPeripheral::isCentralConnected)
    {
      delay(100);
    }

    // Although BLE is connected by now, we need to add an extra wait to make sure all the BLE callbacks are setup and ready to go
    delay(1000);
  }

  // Record audio data and copy it into one big DMA copy buffer
  bool RecordAudioData()
  {
    size_t numBytesRead;
    uint32_t numBytesRecorded = 0;
   
    DebugPrintf("\nRecording %d seconds of audio...\n", TotalSecondsToRecord);

    while (numBytesRecorded < TotalAudioSizeInBytes)
    {
      // Read data from DMA buffers into our copy buffer
      if (i2s_read(I2S_NUM_0, (void*)DMACopyBuffer, DMACopyBufferSizeInBytes, &numBytesRead, portMAX_DELAY) == ESP_OK)
      {
        numBytesRecorded += numBytesRead;
        DebugPrintf("    %u%%\n", numBytesRecorded * 100 / TotalAudioSizeInBytes);
      }
      else
      {
        DebugPrintln("ERROR: reading I2S failed!");
        return false;
      }
    }

    DebugPrintln("Done\n");
    return true;
  }

  // Send a simple header package to the phone
  void SendHeaderToPhone(uint8_t* string, uint32_t stringLength, uint32_t value)
  {
    uint8_t command[stringLength + sizeof(value)];
    memcpy(command, string, stringLength);
    memcpy(&command[stringLength], (uint8_t*)&value, sizeof(value));
    BLEPeripheral::SendData(command, sizeof(command), DelayForPhoneUIToUpdate);
  }

  // Send the audio data in the one big DMA copy buffer to phone using BLE
  void SendAudioDataToPhone()
  {
    DebugPrintln("Send audio data to phone");

    if (BLEPeripheral::isCentralConnected)
    {
      // Let the phone know that the data transfer is starting and how many bytes to expect, e.g. TRANSFER 64000
      SendHeaderToPhone(CommandStartTransfer, sizeof(CommandStartTransfer), DMACopyBufferSizeInBytes);

      uint32_t numBytesSent = 0;
      uint32_t numByteLeftToSend = DMACopyBufferSizeInBytes - numBytesSent;
      uint32_t numBytesToSend = (numByteLeftToSend > MaxBLEBytesPerPacket) ? MaxBLEBytesPerPacket : numByteLeftToSend;

      while (numBytesSent < DMACopyBufferSizeInBytes)
      {
        numByteLeftToSend = DMACopyBufferSizeInBytes - numBytesSent;
        numBytesToSend = (numByteLeftToSend > MaxBLEBytesPerPacket) ? MaxBLEBytesPerPacket : numByteLeftToSend;

        BLEPeripheral::SendData(&DMACopyBuffer[numBytesSent], numBytesToSend);
        numBytesSent += numBytesToSend;

  #ifdef DEBUG
        // Show a simple progress indicator while data is being transferred
        if ((numBytesSent % (MaxBLEBytesPerPacket * 100) == 0))
        DebugPrintf(".");
  #endif
      }
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

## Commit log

2026-01-19 Initial commit
    Initial commit
    [AllParts.stl]
2026-03-10 Minor updates
    - Add a double check for false negatives
    - Update Readme with extra power measurements
